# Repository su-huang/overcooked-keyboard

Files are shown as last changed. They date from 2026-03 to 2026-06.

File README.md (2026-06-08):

# custom end-to-end mechanical keyboard + joystick 
this repository documents the end-to-end hardware engineering of a specialized mechanical keyboard for overcooked2. unlike traditional boards, this project focuses on low-latency analog integration and includes a dedicated joystick to allow for 360-degree movement while maintaining the tactile precision of mechanical switches.

##
i'm currently in the schematic capture and pcb design phase, exploring custom electrical architecture.

key areas of development: 
* joystick integration: developing the circuitry to interface an analog thumbstick (via adc pins) alongside a traditional switch matrix
* circuit analysis: conducting research into matrix scanning logic and signal integrity to ensure zero-latency response times during peak gameplay
* pcb layout: routing the traces for a custom form factor, prioritizing ergonomic joystick placement to reduce thumb strain

roadmap: 
  * custom firmware: writing specialized qmk/zmk logic to map the joystick as an x-input controller or high-speed directional keys
  * fabrication: sending the first revision of the pcb for manufacturing and hand-soldering the smd components
  * enclosure design: cad modelling a low-profile case that supports the extra vertical height of the joystick assembly
  * custom configuration gui: allowing real-time customization without requiring the user to recompile c code or flash firmware manually

technical stack: 
  * eda: kicad 
  * cad: onshape 
  * microcontroller: rp2040
  * input hardware: mechanical switches + 2-axis analog potentiometer
  * firmware: qmk with custom analog-to-hid mapping logic
  * target performance: 1000hz polling rate for frame-perfect dashing

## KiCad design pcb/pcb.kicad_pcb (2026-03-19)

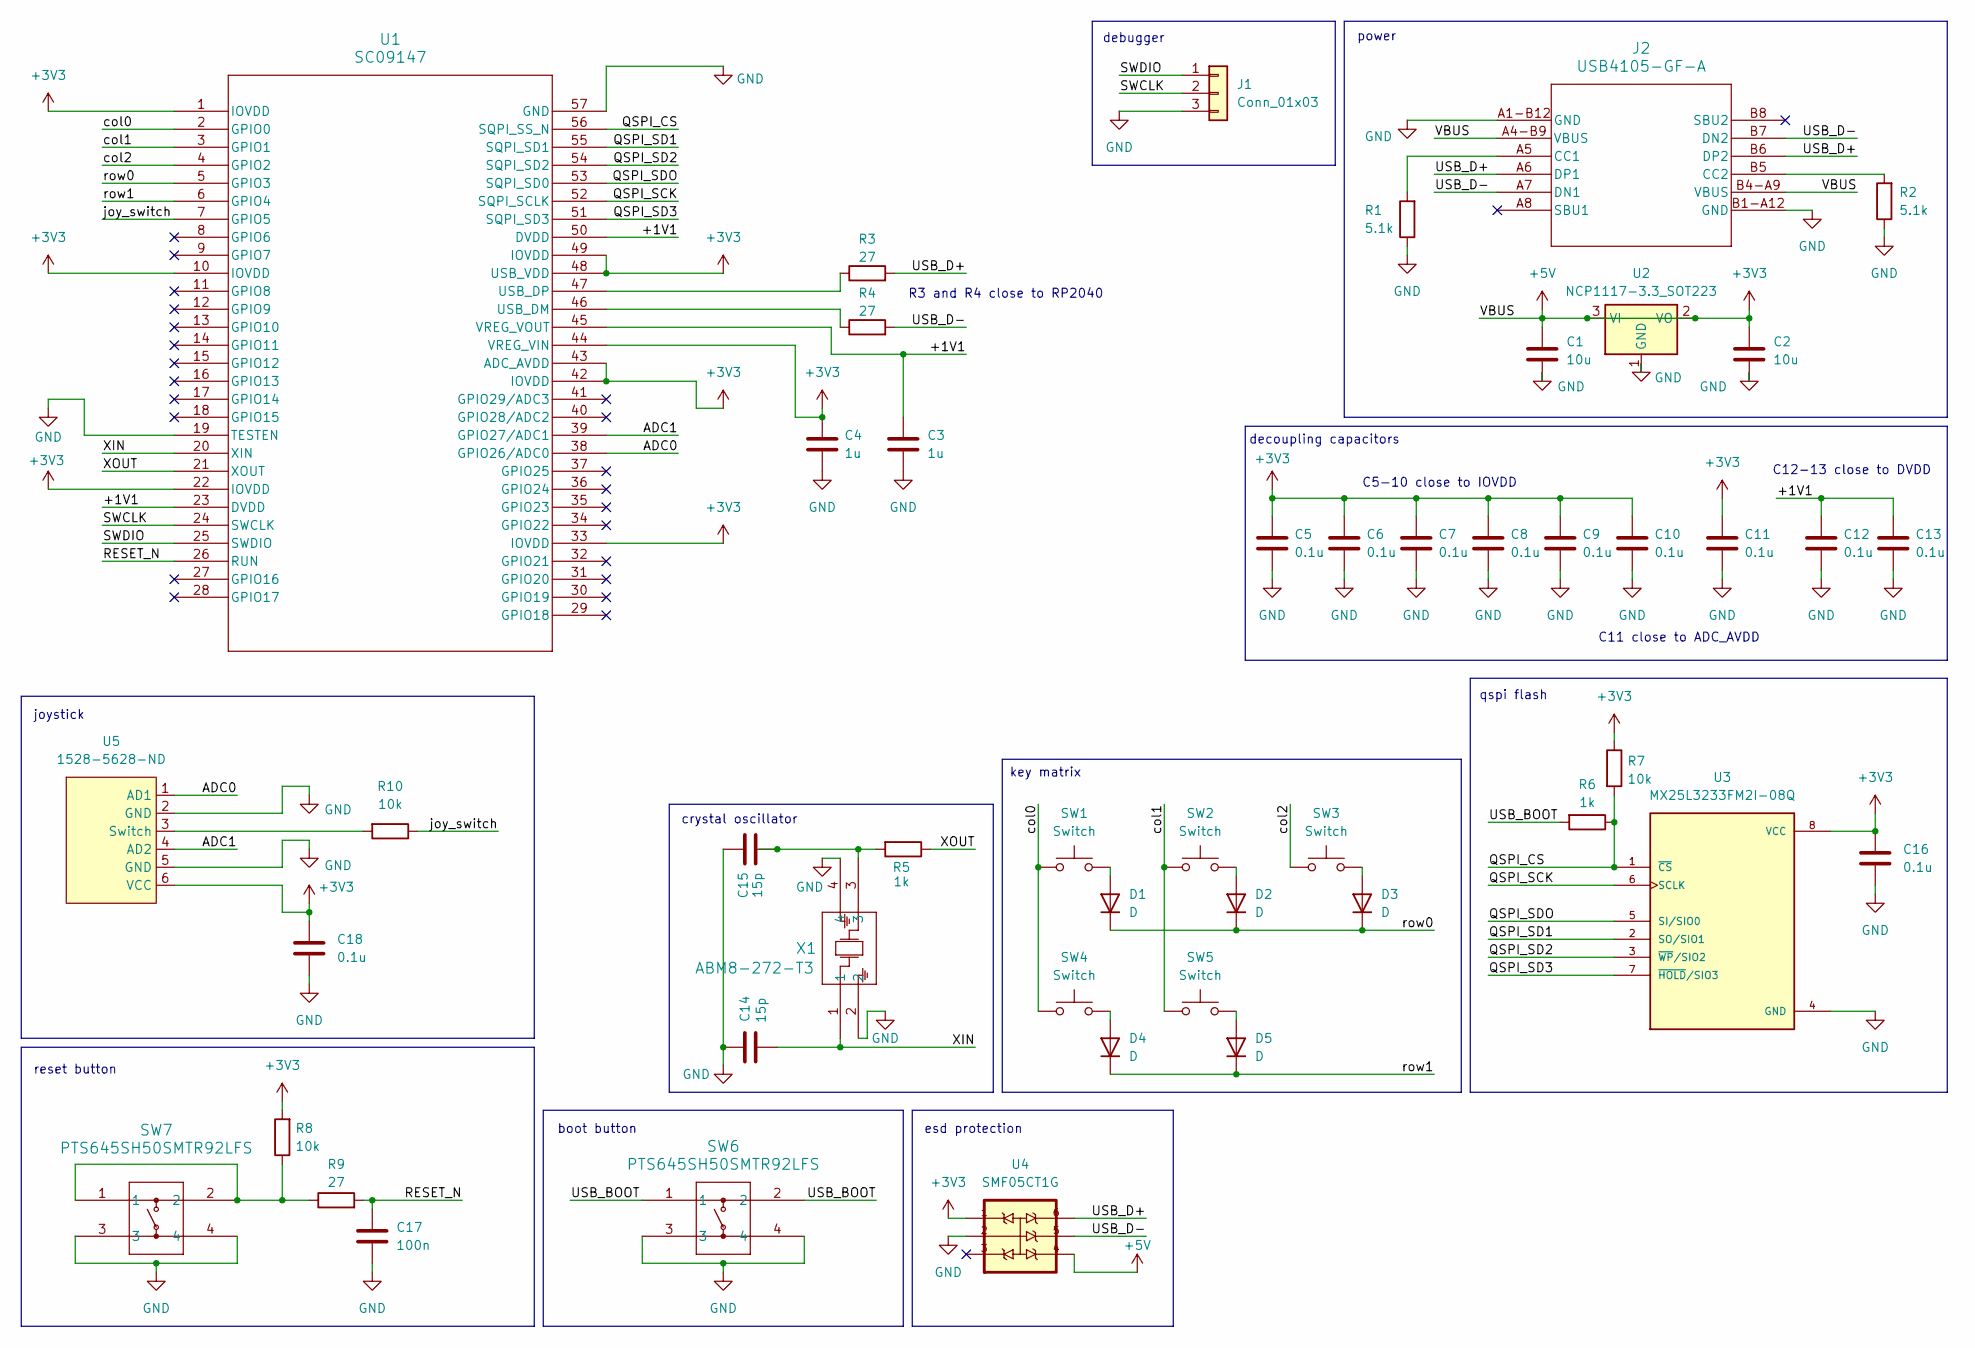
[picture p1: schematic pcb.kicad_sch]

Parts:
C1, C2: 10u; C_0201_0603Metric
C3, C4: 1u; C_0201_0603Metric
C5, C6, C7, C8, C9, C10, C11, C12, C13, C16, C18: 0.1u; C_0201_0603Metric
C14, C15: 15p; C_0201_0603Metric
C17: 100n; C_0201_0603Metric
D1, D2, D3, D4, D5: D; D_0201_0603Metric
J1: Conn_01x03; PinHeader_1x03_P2.54mm_Horizontal
J2: USB4105-GF-A; USB4105_GCT
R1, R2: 5.1k; R_0201_0603Metric
R3, R4, R9: 27; R_0201_0603Metric
R5, R6: 1k; R_0201_0603Metric
R7, R8, R10: 10k; R_0201_0603Metric
SW1, SW2, SW3, SW4, SW5: Switch; SW_SPST_TL3342
SW6, SW7: PTS645SH50SMTR92LFS; PTS645SL50SMTR92 LFS
U1: SC09147; SC09147_QFN56_7X7_RPI
U2: NCP1117-3.3_SOT223; SOT-223-3_TabPin2
U3: MX25L3233FM2I-08Q
U4: SMF05CT1G; SOT65P210X110-6N
U5: 1528-5628-ND
X1: ABM8-272-T3; XTAL_ABM8-272-T3

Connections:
/+1V1: C3.1, C12.1, C13.1, U1.23 (DVDD), U1.45 (VREG_VOUT), U1.50 (DVDD)
/ADC0: U1.38 (GPIO26/ADC0), U5.1 (AD1)
/ADC1: U1.39 (GPIO27/ADC1), U5.4 (AD2)
/QSPI_CS: R6.1, R7.2, U1.56 (SQPI_SS_N), U3.1 (~CS)
/QSPI_SCK: U1.52 (SQPI_SCLK), U3.6 (SCLK)
/QSPI_SD1: U1.55 (SQPI_SD1), U3.2 (SO/SIO1)
/QSPI_SD2: U1.54 (SQPI_SD2), U3.3 (~WP/SIO2)
/QSPI_SD3: U1.51 (SQPI_SD3), U3.7 (~HOLD/SIO3)
/QSPI_SDO: U1.53 (SQPI_SD0), U3.5 (SI/SIO0)
/RESET_N: C17.1, R9.2, U1.26 (RUN)
/SWCLK: J1.2, U1.24 (SWCLK)
/SWDIO: J1.1, U1.25 (SWDIO)
/USB_BOOT: R6.2, SW6.1, SW6.2
/USB_D+: J2.A6 (DP1), J2.B6 (DP2), R3.2, U4.6
/USB_D-: J2.A7 (DN1), J2.B7 (DN2), R4.2, U4.5
/XIN: C14.1, U1.20 (XIN), X1.1
/XOUT: R5.1, U1.21 (XOUT)
/col0: SW1.1, SW4.1, U1.2 (GPIO0)
/col1: SW2.1, SW5.1, U1.3 (GPIO1)
/col2: SW3.1, U1.4 (GPIO2)
/joy_switch: R10.1, U1.7 (GPIO5)
/row0: D1.1 (K), D2.1 (K), D3.1 (K), U1.5 (GPIO3)
/row1: D4.1 (K), D5.1 (K), U1.6 (GPIO4)
GND: C1.2, C2.2, C3.2, C4.2, C5.2, C6.2, C7.2, C8.2, C9.2, C10.2, C11.2, C12.2, C13.2, C14.2, C15.1, C16.2, C17.2, C18.2, J1.3, J2.A1-B12 (GND), J2.B1-A12 (GND), R1.1, R2.1, SW6.3, SW6.4, SW7.3, SW7.4, U1.19 (TESTEN), U1.57 (GND), U2.1 (GND), U3.4 (GND), U4.2, U5.2 (GND), U5.5 (GND), X1.2, X1.4
unnamed: C15.2, R5.2, X1.3
unnamed: D1.2 (A), SW1.2
unnamed: D2.2 (A), SW2.2
unnamed: D3.2 (A), SW3.2
unnamed: D4.2 (A), SW4.2
unnamed: D5.2 (A), SW5.2
unnamed: J2.A5 (CC1), R1.2
unnamed: J2.B5 (CC2), R2.2
unnamed: R8.1, R9.1, SW7.1, SW7.2
unnamed: R4.1, U1.46 (USB_DM)
unnamed: R3.1, U1.47 (USB_DP)
unnamed: R10.2, U5.3 (Switch)

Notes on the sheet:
joystick
R3 and R4 close to RP2040
crystal oscillator
esd protection
power
boot button
reset button
key matrix
debugger
qspi flash
C5-10 close to IOVDD
decoupling capacitors
C12-13 close to DVDD
C11 close to ADC_AVDD

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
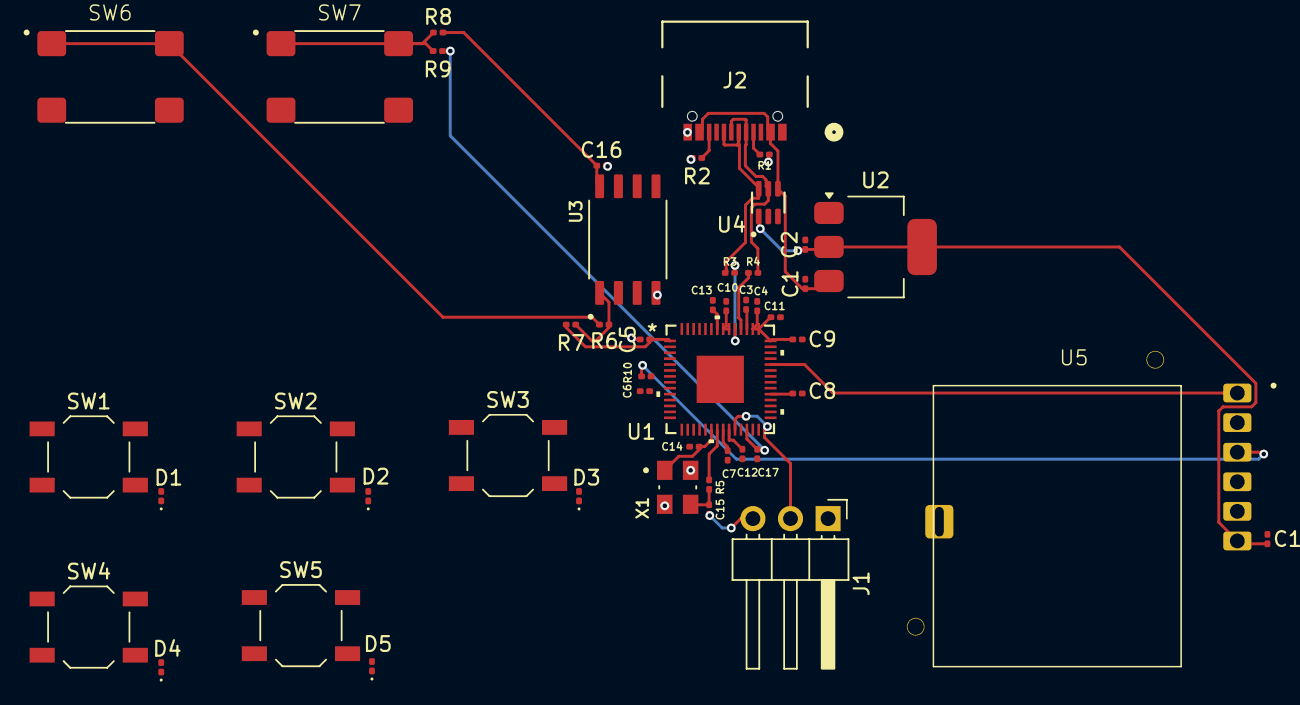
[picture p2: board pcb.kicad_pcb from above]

Board: 2 copper layers, 48 parts (0 on the bottom side), 38 nets.

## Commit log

2026-02-05 imported rp2040 symbol and footprint
    [keyboard_pcb_design.kicad_pcb, keyboard_pcb_design.kicad_sch]
2026-02-05 completed input supply schematic
    [keyboard_pcb_design.kicad_sch]
2026-02-07 completed decoupling capacitors schematics
    [keyboard_pcb_design.kicad_sch]
2026-02-08 uploaded crystal symbol and footprint
2026-02-08 saved crystal oscillator schematic
    [keyboard_pcb_design.kicad_sch]
2026-02-10 flash storage schematic wip
    [keyboard_pcb_design.kicad_sch]
2026-02-10 uploaded flash storage symbol and footprint
2026-02-11 completed qspi flash storage schematic
    [keyboard_pcb_design.kicad_sch]
2026-02-15 add switch library
2026-02-16 key matrix schematic
    [keyboard_pcb_design.kicad_sch]
2026-02-16 change switch library
2026-02-16 tvs diode for esd protection
2026-02-16 complete esd protection schematic
    [keyboard_pcb_design.kicad_sch]
2026-02-18 update usbc and add footprints
2026-02-18 saved changes
    [keyboard_pcb_design.kicad_sch]
2026-02-19 update usb symbol and add switch button
2026-02-19 update schematic for to usbc 16p and reset/boot buttons
    [keyboard_pcb_design.kicad_sch]
2026-03-03 debug conn schematic
    [keyboard_pcb_design.kicad_sch]
2026-03-03 fix iovdd connection
    [keyboard_pcb_design.kicad_sch]
2026-03-07 create joystick footprint
2026-03-07 complete joystick schematic
    [keyboard_pcb_design.kicad_sch]
2026-03-09 update custom footprints
2026-03-09 assign footprints to symbols
    [keyboard_pcb_design.kicad_sch]
2026-03-19 begin pcd layout
    [keyboard_pcb_design.kicad_pcb]
